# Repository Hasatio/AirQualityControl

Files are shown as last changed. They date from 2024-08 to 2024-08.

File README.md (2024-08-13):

# Air Quality Control

The circuit taken as an example while designing the board [Sparkfun BME688](https://www.sparkfun.com/products/19096)

## Revision 0

### Added:

- 1x TCA9406 (Voltage Level Translator)
- 1x PCA9554 (I/O Expander)
- 8x Relay
- 1x K7805-2000R3L or K7805-2000R3 for 5V supply

### Changed:

- Logo

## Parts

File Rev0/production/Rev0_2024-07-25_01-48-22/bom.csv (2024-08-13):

Designator | Footprint | Quantity | Value | LCSC Part #
A0, A1, A2, ADDR0, LED0, LED1, LED2, LED3, LED4, LED5, LED6, LED7, LED8, LED9 | SolderJumper-2_P1.3mm_Bridged_Pad1.0x1.5mm | 14 | SolderJumper_2_Bridged
C1, C2, C7, C8 | 0603 | 4 | 0.1uF
C3, C6 | C_Radial_D10.0mm_H20.0mm_P5.00mm | 2 | 1000uF/35v
C4 | 0805 | 1 | 10uF/100v
C5 | 0603 | 1 | 10uF
D1 | 0603 | 1 | GREEN
D10, D11, D4, D5, D6, D7, D8, D9 | D_SOD-123 | 8 | 1N4148W
D12, D13, D14, D15, D16, D17, D18, D19 | 0603 | 8 | BLUE
D2 | 0603 | 1 | RED
D3 | D_SMA | 1 | Z1SMA4740
FRAME1 | CREATIVE_COMMONS | 1 | FRAME-LETTER
J1 | PhoenixContact_MC_1,5_2-G-3.5_1x02_P3.50mm_Horizontal | 1 | TERMBLOCK_1X2
J2, J4 | 1X04_1MM_RA_STRESSRELIEF | 2 | QWIIC_RIGHT_ANGLE
J3, J5 | PinHeader_1x05_P2.54mm_Vertical | 2 | Conn_01x05
JP10, JP11, JP12, JP13, JP14, JP15, JP16, JP9 | PhoenixContact_MC_1,5_3-G-3.5_1x03_P3.50mm_Horizontal | 8 | HEADER-1X3_508TERM
JP3, JP4, JP7, JP8 | STAND-OFF | 4 | STAND-OFF
K1, K2, K3, K4, K5, K6, K7, K8 | Relay_SPDT_Omron-G5Q-1 | 8 | G5Q-1
Q1 | TO252 | 1 | AOD417
Q2, Q3, Q4, Q5, Q6, Q7, Q8, Q9 | SOT-23 | 8 | MMBT2222
R1, R10, R2, R3, R38, R39, R4, R40, R41, R42, R43, R44, R45, R5, R6, R7, R8, R9 | 0603 | 18 | 10K
R11 | 0603 | 1 | 100k
R12 | 0603 | 1 | 2k2
R13, R46, R47, R48, R49, R50, R51, R52, R53 | 0603 | 9 | 1k
R14, R15, R16, R17, R18, R19, R20, R21 | 0603 | 8 | 380R
R22, R24, R26, R28, R30, R32, R34, R36 | 0603 | 8 | 330R
R23, R25, R27, R29, R31, R33, R35, R37 | 0603 | 8 | 10
Sign-RecyclBin | LOGO_RECYCLEBIN_1 | 1
Sign_Pb-Free | LOGO_PBFREE | 1
Sign_RoHS | LOGO_ROHS_1 | 1 | Val**
U1 | Bosch_LGA-8_3x3mm_P0.8mm_ClockwisePinNumbering | 1 | BME688
U10, U11, U12, U5, U6, U7, U8, U9 | SMDIP-4_W9.53mm | 8 | LTV-817S
U2 | SSOP-8_2.95x2.8mm_P0.65mm | 1 | TCA9406DC
U3 | Converter_DCDC_RECOM_R-78HB-0.5L_THT | 1 | K7805-2000R3L
U4 | TSSOP-16_4.4x5mm_P0.65mm | 1 | TCA9554

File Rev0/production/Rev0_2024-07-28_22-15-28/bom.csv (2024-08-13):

Designator | Footprint | Quantity | Value | LCSC Part #
C1, C11, C12, C2, C6 | 0603 | 5 | 0.1uF
C10, C3 | C_Radial_D10.0mm_H20.0mm_P5.00mm | 2 | 1000uF/35v
C4, C5 | 0603 | 2 | 4.7uF-50V
C7 | 0603 | 1 | 47pF-5%-X7R
C8, C9 | 0603 | 2 | 22uF
D1 | D_SMA | 1 | Z1SMA4740
D10 | 0603 | 1 | GREEN
D11 | 0603 | 1 | RED
D12, D13, D14, D15, D16, D17, D18, D19 | 0603 | 8 | BLUE
D2, D3, D4, D5, D6, D7, D8, D9 | D_SOD-123 | 8 | 1N4148W
J1 | PhoenixContact_MC_1,5_2-G-3.5_1x02_P3.50mm_Horizontal | 1 | TERMBLOCK_1X2
J2, J4 | 1X04_1MM_RA_STRESSRELIEF | 2 | QWIIC_RIGHT_ANGLE
J3, J5 | PinHeader_1x05_P2.54mm_Vertical | 2 | Conn_01x05
JP1, JP2, JP3, JP4, JP5, JP6, JP7, JP8 | PhoenixContact_MC_1,5_3-G-3.5_1x03_P3.50mm_Horizontal | 8 | HEADER-1X3_508TERM
K1, K2, K3, K4, K5, K6, K7, K8 | Relay_SPDT_Omron-G5Q-1 | 8 | G5Q-1
L1 | L_7.3x7.3_H4.5 | 1 | 6.8uH
Q1 | TO252 | 1 | AOD417
Q2, Q3, Q4, Q5, Q6, Q7, Q8, Q9 | SOT-23 | 8 | MMBT2222
R1, R10, R11, R12, R13, R2, R3, R38, R39, R4, R40, R41, R42, R43, R44, R45, R5, R54, R7 | 0603 | 19 | 10K
R14, R15, R16, R17, R18, R19, R20, R21 | 0603 | 8 | 360R
R22, R24, R26, R28, R30, R32, R34, R36 | 0603 | 8 | 330R
R23, R25, R27, R29, R31, R33, R35, R37 | 0603 | 8 | 10
R46, R47, R48, R49, R50, R51, R52, R53, R56 | 0603 | 9 | 1K
R55 | 0603 | 1 | 2k2
R6 | 0603 | 1 | 100k
R8 | 0603 | 1 | 220k
R9 | 0603 | 1 | 41.2k
Sign-RecyclBin | LOGO_RECYCLEBIN_1 | 1
Sign_Pb-Free | LOGO_PBFREE | 1
Sign_RoHS | LOGO_ROHS_1 | 1 | Val**
U1 | Bosch_LGA-8_3x3mm_P0.8mm_ClockwisePinNumbering | 1 | BME688
U10, U11, U12, U5, U6, U7, U8, U9 | SMDIP-4_W9.53mm | 8 | LTV-817S
U2 | SSOP-8_2.95x2.8mm_P0.65mm | 1 | TCA9406DC
U3 | V-DFN3020-13 | 1 | AP63357
U4 | TSSOP-16_4.4x5mm_P0.65mm | 1 | TCA9554

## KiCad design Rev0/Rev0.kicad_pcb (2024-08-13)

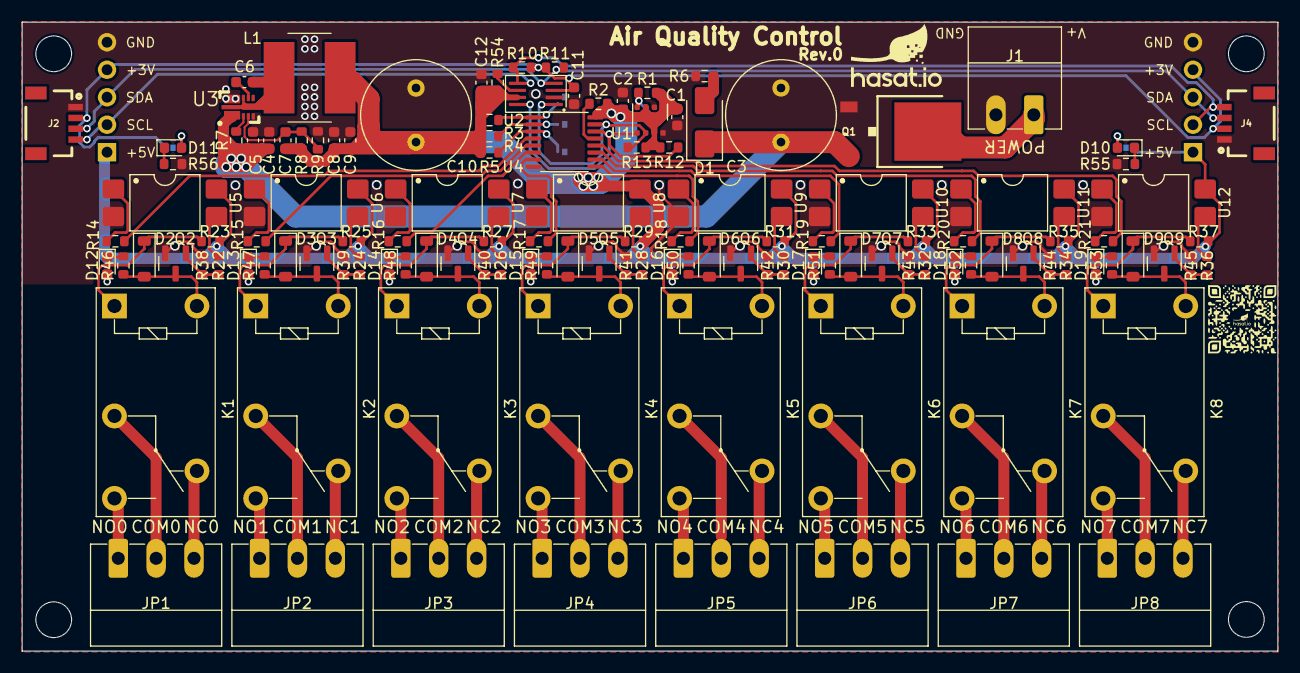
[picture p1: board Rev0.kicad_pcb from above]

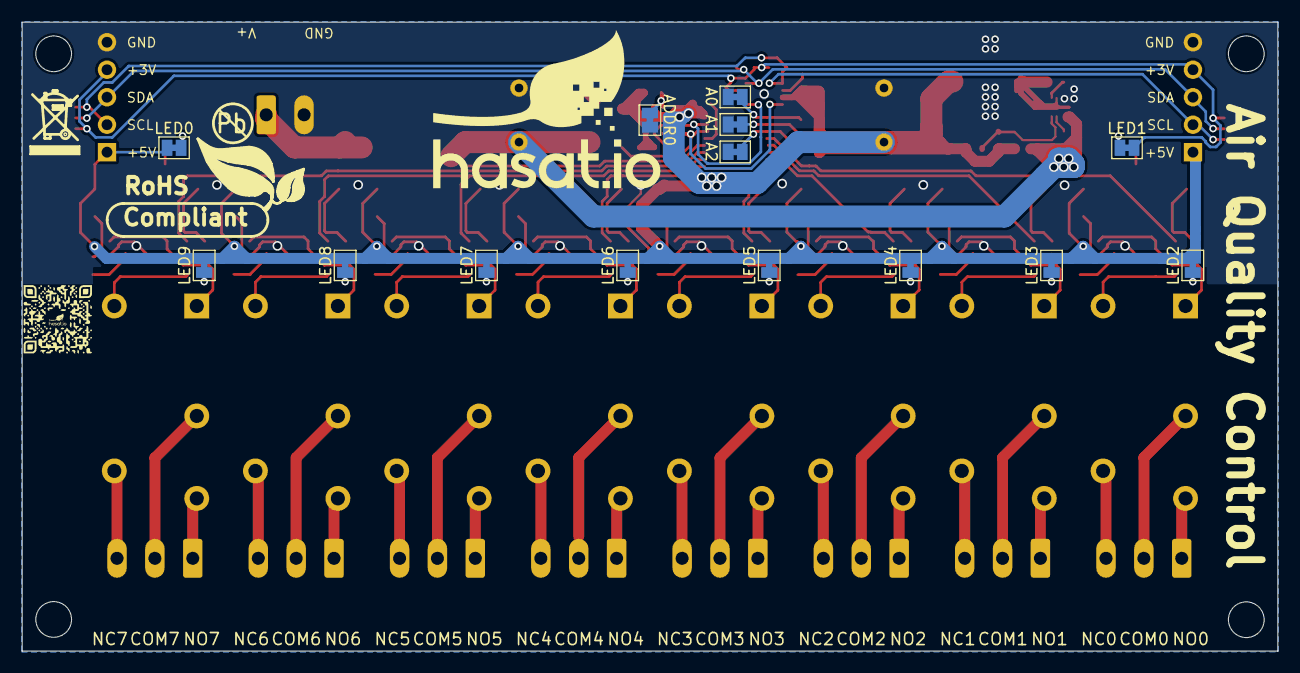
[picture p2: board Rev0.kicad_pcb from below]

Board: 2 copper layers, 116.0 x 58.1 mm, 147 parts (17 on the bottom side), 112 nets.

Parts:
A0, A1, A2: SolderJumper_2_Bridged; SolderJumper-2_P1.3mm_Bridged_Pad1.0x1.5mm
ADDR0: SolderJumper_2_Bridged; SolderJumper-2_P1.3mm_Bridged_Pad1.0x1.5mm
C1, C2, C6, C11, C12: 0.1uF; C_0603_1608Metric
C3, C10: 1000uF/35v; C_Radial_D10.0mm_H20.0mm_P5.00mm
C4, C5: 4.7uF-50V; C_0603_1608Metric
C7: 47pF-5%-X7R; C_0603_1608Metric
C8, C9: 22uF; C_0603_1608Metric
D1: Z1SMA4740; D_SMA
D2, D3, D4, D5, D6, D7, D8, D9: 1N4148W; D_SOD-123
D10: GREEN; LED_0603_1608Metric
D11: RED; LED_0603_1608Metric
D12, D13, D14, D15, D16, D17, D18, D19: BLUE; LED_0603_1608Metric
J1: TERMBLOCK_1X2; PhoenixContact_MC_1,5_2-G-3.5_1x02_P3.50mm_Horizontal
J2, J4: QWIIC_RIGHT_ANGLE; 1X04_1MM_RA_STRESSRELIEF
J3, J5: Conn_01x05; PinHeader_1x05_P2.54mm_Vertical
JP1, JP2, JP3, JP4, JP5, JP6, JP7, JP8: HEADER-1X3_508TERM; PhoenixContact_MC_1,5_3-G-3.5_1x03_P3.50mm_Horizontal
K1, K2, K3, K4, K5, K6, K7, K8: G5Q-1; Relay_SPDT_Omron-G5Q-1
L1: 6.8uH; L_Bourns_SRN8040TA
LED0, LED1, LED2, LED3, LED4, LED5, LED6, LED7, LED8, LED9: SolderJumper_2_Bridged; SolderJumper-2_P1.3mm_Bridged_Pad1.0x1.5mm
Q1: AOD417; TO252
Q2, Q3, Q4, Q5, Q6, Q7, Q8, Q9: MMBT2222; SOT-23
R1, R2, R3, R4, R5, R10, R11, R12, R13, R38, R39, R40, R41, R42, R43, R44, R45, R54: 10K; R_0603_1608Metric
R6: 100k; R_0603_1608Metric
R7: 10k; R_0603_1608Metric
R8: 158k; R_0603_1608Metric
R9: 30k; R_0603_1608Metric
R14, R15, R16, R17, R18, R19, R20, R21: 360R; R_0603_1608Metric
R22, R24, R26, R28, R30, R32, R34, R36: 330R; R_0603_1608Metric
R23, R25, R27, R29, R31, R33, R35, R37: 10R; R_0603_1608Metric
R46, R47, R48, R49, R50, R51, R52, R53: 1K; R_0603_1608Metric
R55: 2k2; R_0603_1608Metric
R56: 1k; R_0603_1608Metric
Sign-RecyclBin: LOGO_RECYCLEBIN_1
Sign_Pb-Free: LOGO_PBFREE
Sign_RoHS: Val**; LOGO_ROHS_1
U1: BME688; Bosch_LGA-8_3x3mm_P0.8mm_ClockwisePinNumbering
U2: TCA9406DC; SSOP-8_2.95x2.8mm_P0.65mm
U3: AP63357; V-DFN3020-13
U4: TCA9534A; TSSOP-16_4.4x5mm_P0.65mm
U5, U6, U7, U8, U9, U10, U11, U12: LTV-817S; SMDIP-4_W9.53mm

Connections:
+3.3V: C11.1, J2.2, J3.4, J4.2, J5.4, LED1.1 (A), R10.1, R11.1, U2.3 (VCCA)
+5V: C1.1, C2.1, C7.1, C8.1, C9.1, C10.1, C12.1, J3.1, J5.1, L1.2, LED0.1 (A), LED2.1 (A), LED3.1 (A), LED4.1 (A), LED5.1 (A), LED6.1 (A), LED7.1 (A), LED8.1 (A), LED9.1 (A), R1.2, R2.2, R3.2, R4.2, R5.2, R8.2, R12.1, R13.1, R23.1, R25.1, R27.1, R29.1, R31.1, R33.1, R35.1, R37.1, R54.1, U1.2 (CSB), U1.6 (VDDIO), U1.8 (VDD), U2.7 (VCCB), U4.16 (VDD), U5.4, U6.4, U7.4, U8.4, U9.4, U10.4, U11.4, U12.4
/A0: A0.1 (A), R3.1, U4.1 (A0)
/A1: A1.1 (A), R4.1, U4.2 (A1)
/A2: A2.1 (A), R5.1, U4.3 (A2)
/COM0: JP1.2, K1.2
/COM1: JP2.2, K2.2
/COM2: JP3.2, K3.2
/COM3: JP4.2, K4.2
/COM4: JP5.2, K5.2
/COM5: JP6.2, K6.2
/COM6: JP7.2, K7.2
/COM7: JP8.2, K8.2
/NC0: JP1.3, K1.4
/NC1: JP2.3, K2.4
/NC2: JP3.3, K3.4
/NC3: JP4.3, K4.4
/NC4: JP5.3, K5.4
/NC5: JP6.3, K6.4
/NC6: JP7.3, K7.4
/NC7: JP8.3, K8.4
/NO0: JP1.1, K1.3
/NO1: JP2.1, K2.3
/NO2: JP3.1, K3.3
/NO3: JP4.1, K4.3
/NO4: JP5.1, K5.3
/NO5: JP6.1, K6.3
/NO6: JP7.1, K7.3
/NO7: JP8.1, K8.3
/Out0: R14.2, U4.4 (P0)
/Out1: R15.2, U4.5 (P1)
/Out2: R16.2, U4.6 (P2)
/Out3: R17.2, U4.7 (P3)
/Out4: R18.2, U4.9 (P4)
/Out5: R19.2, U4.10 (P5)
/Out6: R20.2, U4.11 (P6)
/Out7: R21.2, U4.12 (P7)
/Relay0: R22.2, U5.3
/Relay1: R24.1, U6.3
/Relay2: R26.1, U7.3
/Relay3: R28.1, U8.3
/Relay4: R30.1, U9.3
/Relay5: R32.1, U10.3
/Relay6: R34.1, U11.3
/Relay7: R36.1, U12.3
/SCL_A: J2.4, J3.2, J4.4, J5.2, R10.2, U2.5 (SCL_A)
/SCL_B: R12.2, U1.4 (SCK), U2.8 (SCL_B), U4.14 (SCL)
/SDA_A: J2.3, J3.3, J4.3, J5.3, R11.2, U2.4 (SDA_A)
/SDA_B: R13.2, U1.3 (SDI), U2.1 (SDA_B), U4.15 (SDA)
/SDO: ADDR0.1 (A), R1.1, U1.5 (SDO)
GND: A0.2 (B), A1.2 (B), A2.2 (B), ADDR0.2 (B), C1.2, C2.2, C3.2, C4.2, C5.2, C8.2, C9.2, C10.2, C11.2, C12.2, J1.2, J2.1, J3.5, J4.1, J5.5, Q1.1 (G), Q2.2 (E), Q3.2 (E), Q4.2 (E), Q5.2 (E), Q6.2 (E), Q7.2 (E), Q8.2 (E), Q9.2 (E), R6.1, R9.1, R38.1, R39.1, R40.1, R41.1, R42.1, R43.1, R44.1, R45.1, R55.2, R56.2, U1.1 (GND), U1.7 (GND), U2.2 (GND), U3.P$4 (COMP), U3.P$8 (GND), U4.8 (GND), U5.2, U6.2, U7.2, U8.2, U9.2, U10.2, U11.2, U12.2
unnamed: C6.2, L1.1, U3.P$7 (SW), U3.P$9 (SW)
unnamed: D1.2 (A), R6.2
unnamed: D2.2 (A), K1.5, Q2.3 (C), R46.1
unnamed: D2.1 (K), K1.1, R23.2
unnamed: D3.2 (A), K2.5, Q3.3 (C), R47.1
unnamed: D3.1 (K), K2.1, R25.2
unnamed: D4.2 (A), K3.5, Q4.3 (C), R48.1
unnamed: D4.1 (K), K3.1, R27.2
unnamed: D5.2 (A), K4.5, Q5.3 (C), R49.1
unnamed: D5.1 (K), K4.1, R29.2
unnamed: D6.2 (A), K5.5, Q6.3 (C), R50.1
unnamed: D6.1 (K), K5.1, R31.2
unnamed: D7.2 (A), K6.5, Q7.3 (C), R51.1
unnamed: D7.1 (K), K6.1, R33.2
unnamed: D8.2 (A), K7.5, Q8.3 (C), R52.1
unnamed: D8.1 (K), K7.1, R35.2
unnamed: D9.2 (A), K8.5, Q9.3 (C), R53.1
unnamed: D9.1 (K), K8.1, R37.2
unnamed: D10.2 (A), LED0.2 (B)
unnamed: D10.1 (K), R55.1
unnamed: D11.2 (A), LED1.2 (B)
unnamed: D11.1 (K), R56.1
unnamed: D12.2 (A), LED2.2 (B)
unnamed: D12.1 (K), R46.2
unnamed: D13.2 (A), LED3.2 (B)
unnamed: D13.1 (K), R47.2
unnamed: D14.2 (A), LED4.2 (B)
unnamed: D14.1 (K), R48.2
unnamed: D15.2 (A), LED5.2 (B)
unnamed: D15.1 (K), R49.2
unnamed: D16.2 (A), LED6.2 (B)
unnamed: D16.1 (K), R50.2
unnamed: D17.2 (A), LED7.2 (B)
unnamed: D17.1 (K), R51.2
unnamed: D18.2 (A), LED8.2 (B)
unnamed: D18.1 (K), R52.2
unnamed: D19.2 (A), LED9.2 (B)
unnamed: D19.1 (K), R53.2
unnamed: J1.1, Q1.3 (D)
unnamed: Q2.1 (B), R22.1, R38.2
unnamed: Q3.1 (B), R24.2, R39.2
unnamed: Q4.1 (B), R26.2, R40.2
unnamed: Q5.1 (B), R28.2, R41.2
unnamed: Q6.1 (B), R30.2, R42.2
unnamed: Q7.1 (B), R32.2, R43.2
unnamed: Q8.1 (B), R34.2, R44.2
unnamed: Q9.1 (B), R36.2, R45.2
unnamed: R14.1, U5.1
unnamed: R15.1, U6.1
unnamed: R16.1, U7.1
unnamed: R17.1, U8.1
unnamed: R18.1, U9.1
unnamed: R19.1, U10.1
unnamed: R20.1, U11.1
unnamed: R21.1, U12.1
unnamed: R54.2, U2.6 (OE)
unnamed: C6.1, U3.P$6 (BST)
unnamed: R7.1, U3.P$2 (EN)
unnamed: C7.2, R8.1, R9.2, U3.P$3 (FB)
unnamed: R2.1, U4.13 (~INT)
VCC: C3.1, C4.1, C5.1, D1.1 (K), Q1.2 (S), R7.2, U3.P$1 (VIN)
